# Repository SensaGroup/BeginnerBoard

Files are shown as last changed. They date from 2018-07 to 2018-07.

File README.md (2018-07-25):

# BeginnerBoard
BeginnerBoard designed by SENSA for beginners to get into electronics and programming.

## Top View
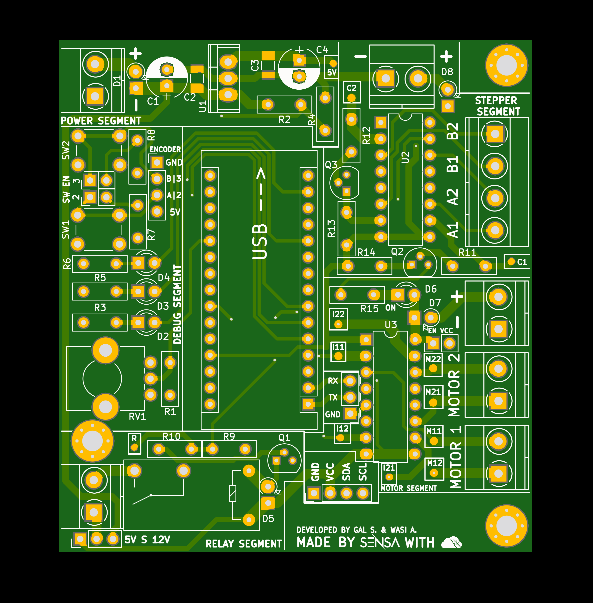
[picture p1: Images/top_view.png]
top_view


## Bottom View
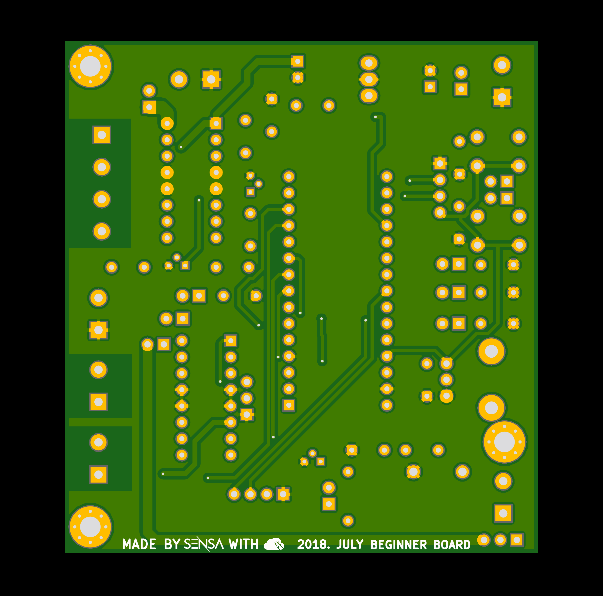
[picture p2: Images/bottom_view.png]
bottom_view


## Specifications
The BeginnerBoard has all the necessary components to get started with Arduino from beginner to advanced level.

### Segments and components
- Power Segment
	- Input of 7V-25V
	- 7805 regulator (output current of 1.5A)
- Arduino NANO
	- One of the most popular Arduino boards with 5V logic
- Debug Segment
	- 3x LEDs
	- 2x Push Buttons or 1x Encoder 
	- 1x POT
- Relay Segment
	- Simple switch relay
	- Adjustable 5V/12V supply
- Stepper Segment
	- Powered by L293D using both drivers
	- Custom input voltage with diode protection 
- Dual Motor Segment
	- Powered by L293D
	- Custon input voltage or Input of 7V-25V from Power Segment
- Pinout for I2C

## Sponsored by AISLER
### Develop and manufacture your own premium boards at [aisler.net](https://aisler.net/)

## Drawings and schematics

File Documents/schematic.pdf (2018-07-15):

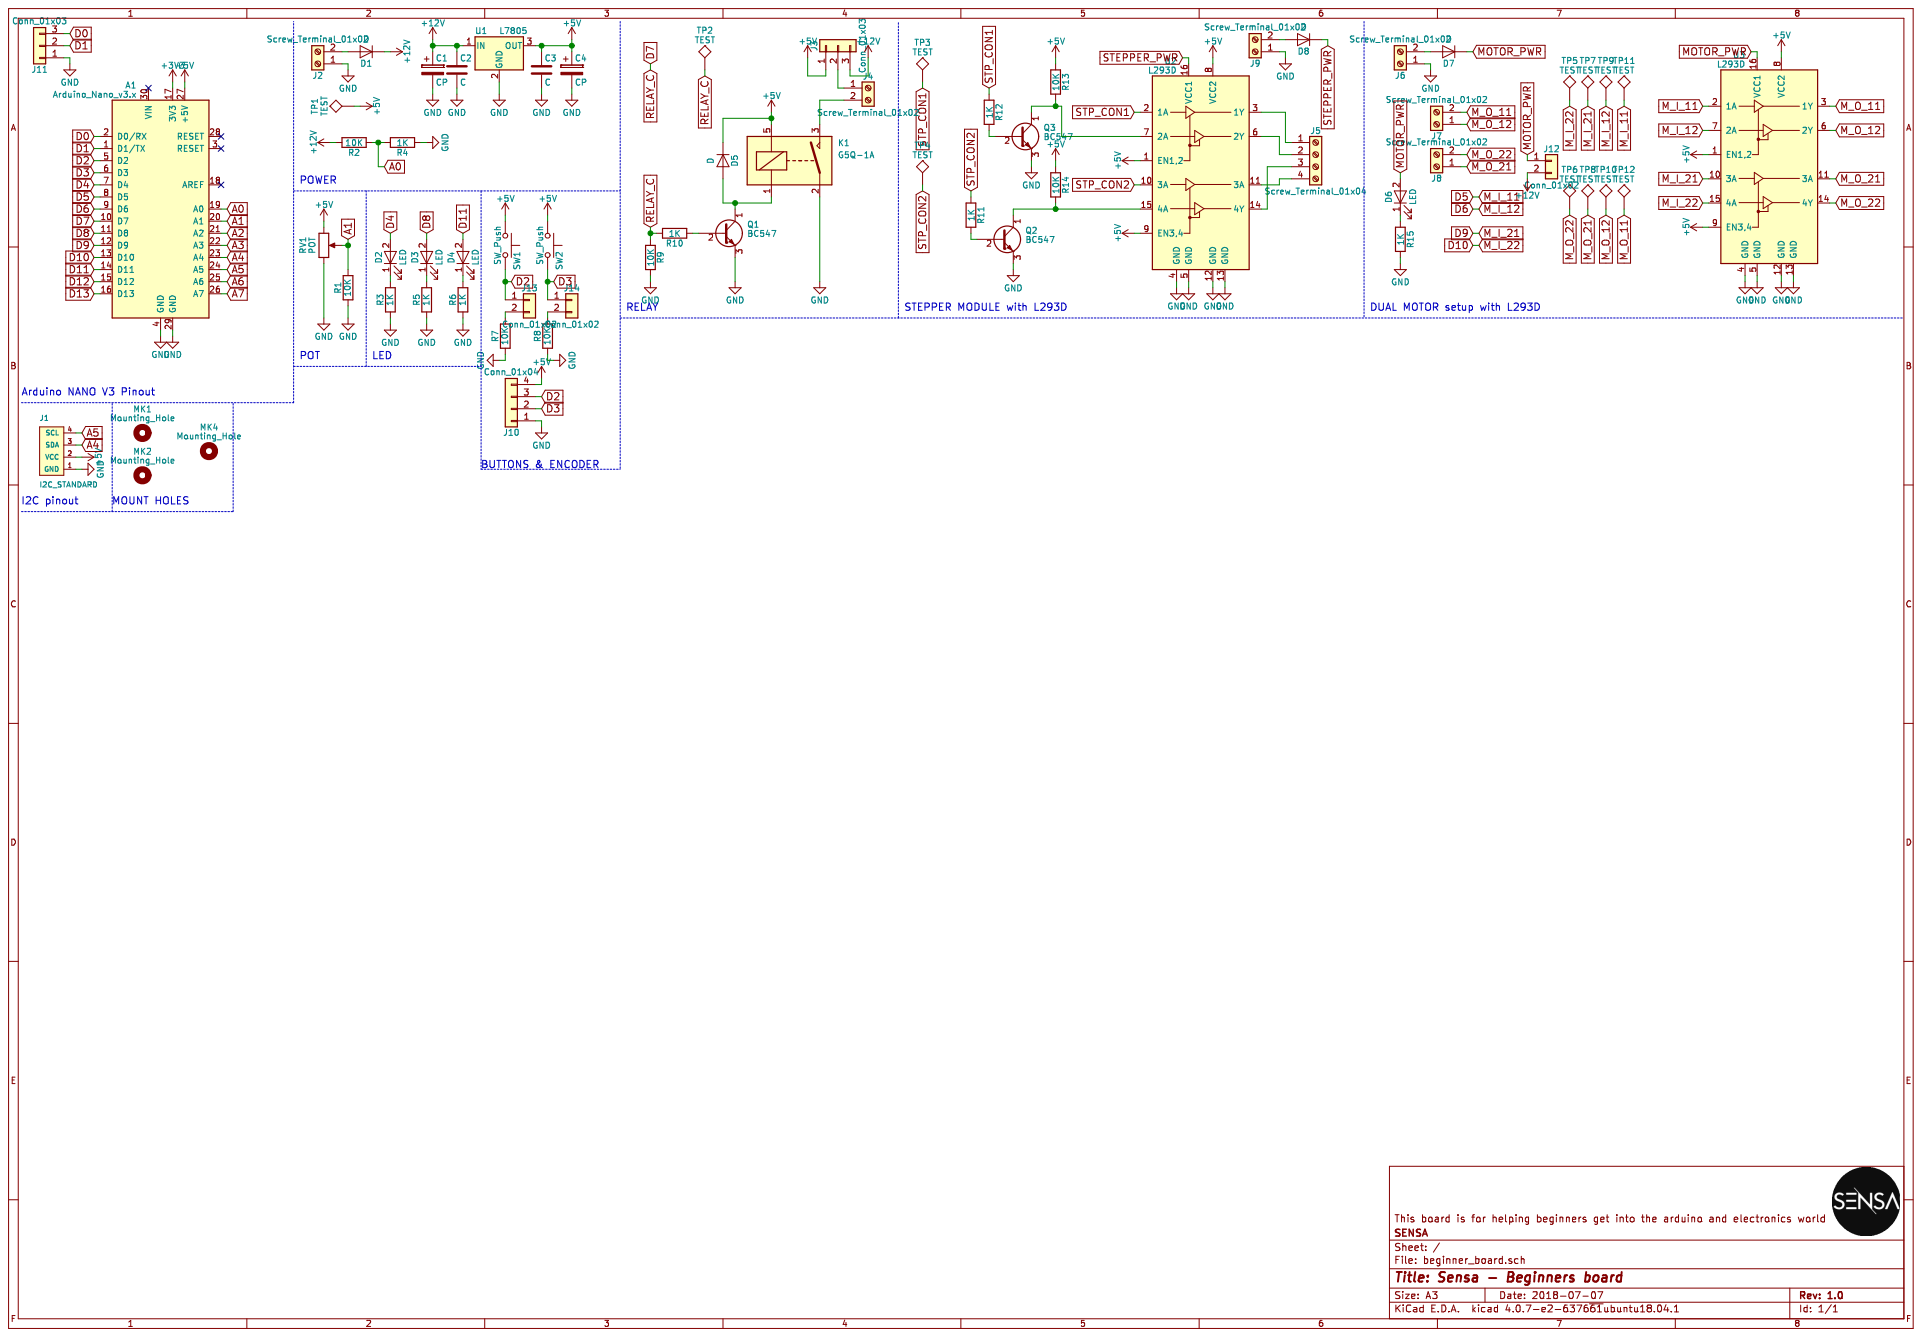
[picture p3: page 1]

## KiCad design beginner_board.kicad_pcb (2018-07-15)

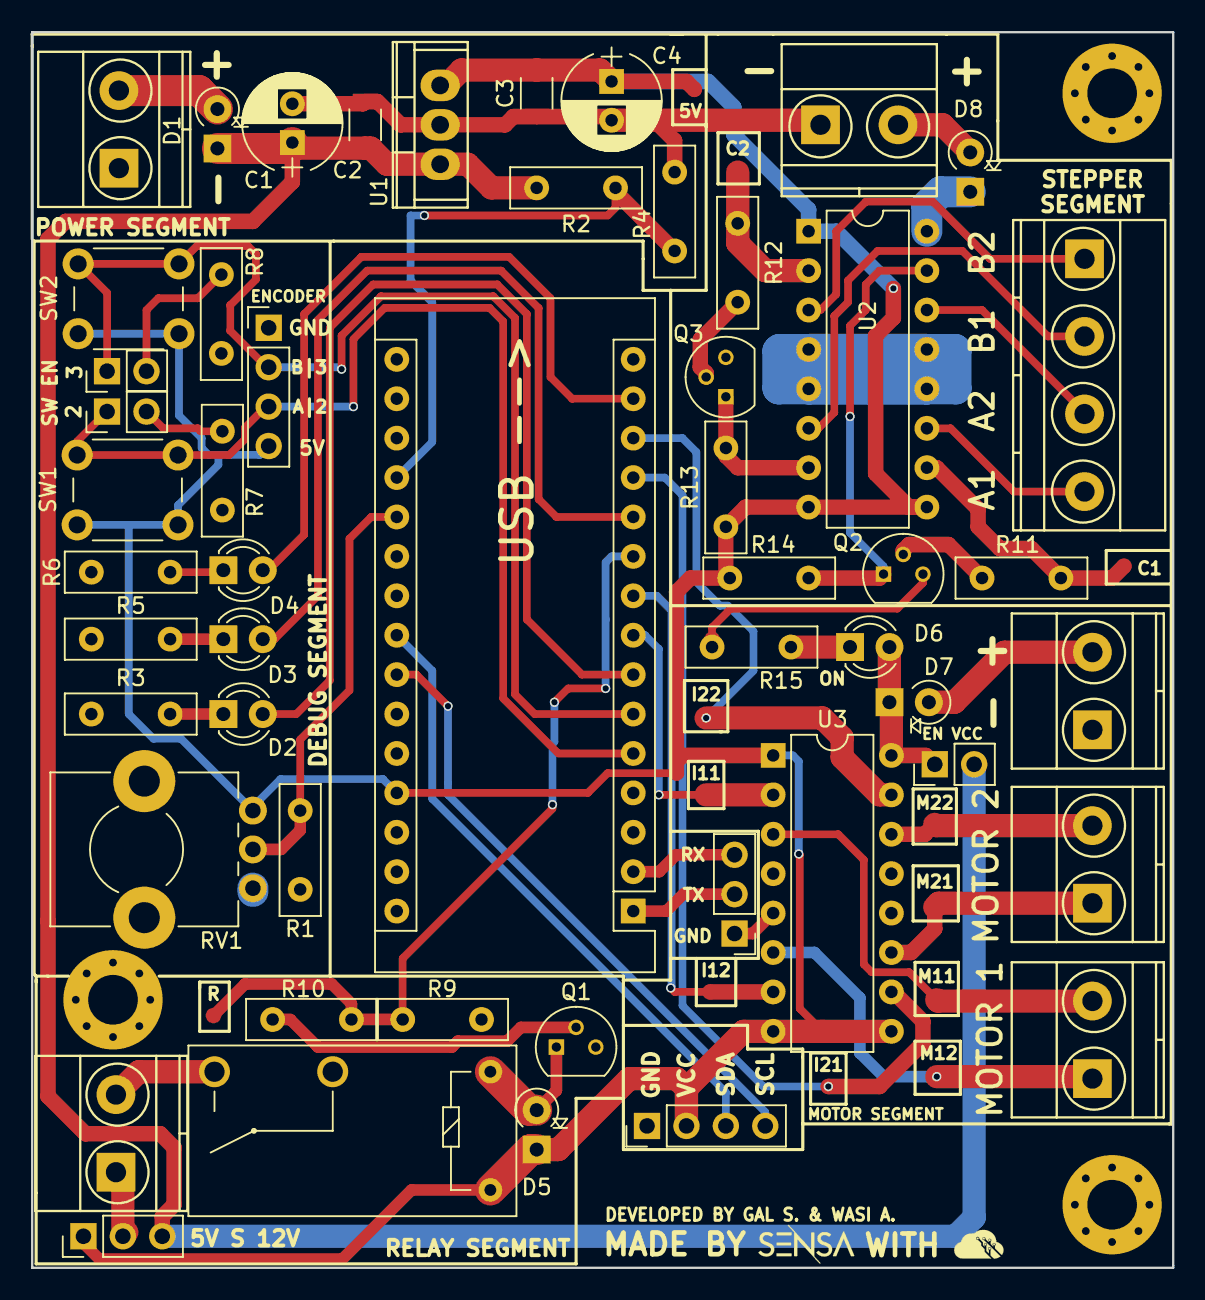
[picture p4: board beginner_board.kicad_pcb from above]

Board: 2 copper layers, 73.5 x 79.6 mm, 67 parts (0 on the bottom side), 48 nets.

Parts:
A1: Arduino_Nano_v3.x; Arduino_Nano
C1, C4: CP; CP_Radial_D6.3mm_P2.50mm
C2, C3: C; C_1206
D1, D5, D7, D8: D; D_A-405_P2.54mm_Vertical_KathodeUp
D2, D3, D4, D6: LED; LED_D3.0mm
J1: I2C_STANDARD; Pin_Header_Straight_1x04_Pitch2.54mm
J2, J4, J6, J7, J8, J9: Screw_Terminal_01x02; TerminalBlock_Phoenix_MKDS1.5-2pol
J3, J11: Conn_01x03; Pin_Header_Straight_1x03_Pitch2.54mm
J5: Screw_Terminal_01x04; TerminalBlock_Phoenix_MKDS1.5-4pol
J10: Conn_01x04; Pin_Header_Straight_1x04_Pitch2.54mm
J12, J13, J14: Conn_01x02; Pin_Header_Straight_1x02_Pitch2.54mm
K1: G5Q-1A; Relay_SPST_OMRON-G5Q
MK1, MK2, MK4: Mounting_Hole; MountingHole_3.2mm_M3_Pad_Via
Q1, Q2, Q3: BC547; TO-92_Molded_Narrow
R1, R2, R7, R8, R9, R13, R14: 10K; R_Box_L8.4mm_W2.5mm_P5.08mm
R3, R4, R5, R6, R10, R11, R12, R15: 1K; R_Box_L8.4mm_W2.5mm_P5.08mm
RV1: POT; Potentiometer_Alps_RK09K_Horizontal
SW1, SW2: SW_Push; SW_PUSH_6mm
TP1, TP2, TP3, TP4, TP5, TP6, TP7, TP8, TP9, TP10, TP11, TP12: TEST; FIDUCIAL-1X2
U1: L7805; TO-220
U2, U3: L293D; DIP-16_W7.62mm

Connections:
+5V: A1.27, C3.1, C4.1, D5.1, J1.2, J3.1, J10.4, K1.5, R13.1, R14.1, RV1.1, SW1.1, SW2.1, TP1.1, U1.3, U2.1, U2.8, U2.9, U3.1, U3.8, U3.9
+12V: C1.1, C2.1, D1.1, J3.3, J12.2, R2.2, U1.1
A0: A1.19, R2.1, R4.2
A1: A1.20, R1.2, RV1.2
A4: A1.23, J1.3
A5: A1.24, J1.4
D0: A1.2, J11.3
D1: A1.1, J11.2
D2: A1.5, J10.3, J13.1, SW1.2
D3: A1.6, J10.2, J14.1, SW2.2
D4: A1.7, D2.2
D5: A1.8, TP11.1, U3.2
D6: A1.9, TP9.1, U3.7
D7: A1.10, R9.1, R10.2, TP2.1
D8: A1.11, D3.2
D9: A1.12, TP7.1, U3.10
D10: A1.13, TP5.1, U3.15
D11: A1.14, D4.2
GND: A1.4, A1.29, C1.2, C2.2, C3.2, C4.2, J1.1, J2.1, J6.1, J9.1, J10.1, J11.1, K1.2, Q1.3, Q2.3, Q3.3, R1.1, R3.1, R4.1, R5.1, R6.1, R7.1, R8.1, R9.2, R15.2, RV1.3, U1.2, U2.4, U2.5, U2.12, U2.13, U3.4, U3.5, U3.12, U3.13
MOTOR_PWR: D6.2, D7.1, J12.1, U3.16
M_O_11: J7.2, TP12.1, U3.3
M_O_12: J7.1, TP10.1, U3.6
M_O_21: J8.1, TP8.1, U3.11
M_O_22: J8.2, TP6.1, U3.14
unnamed: D1.2, J2.2
unnamed: D2.1, R3.2
unnamed: D3.1, R5.2
unnamed: D4.1, R6.2
unnamed: D5.2, K1.1, Q1.1
unnamed: D6.1, R15.1
unnamed: D7.2, J6.2
unnamed: D8.2, J9.2
unnamed: J3.2, J4.1
unnamed: J4.2, K1.3
unnamed: J5.1, U2.3
unnamed: J5.2, U2.6
unnamed: J5.3, U2.14
unnamed: J5.4, U2.11
unnamed: J13.2, R7.2
unnamed: J14.2, R8.2
unnamed: Q1.2, R10.1
unnamed: Q2.1, R14.2, U2.15
unnamed: Q2.2, R11.2
unnamed: Q3.1, R13.2, U2.7
unnamed: Q3.2, R12.2
STEPPER_PWR: D8.1, U2.16
STP_CON1: R12.1, TP3.1, U2.2
STP_CON2: R11.1, TP4.1, U2.10
